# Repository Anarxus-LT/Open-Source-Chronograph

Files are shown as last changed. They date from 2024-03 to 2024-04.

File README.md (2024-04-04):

# Open-Source-Chronograph
 An open source chronograph used to measure the speed and energy of projectiles. Mainly intended for airsoft.
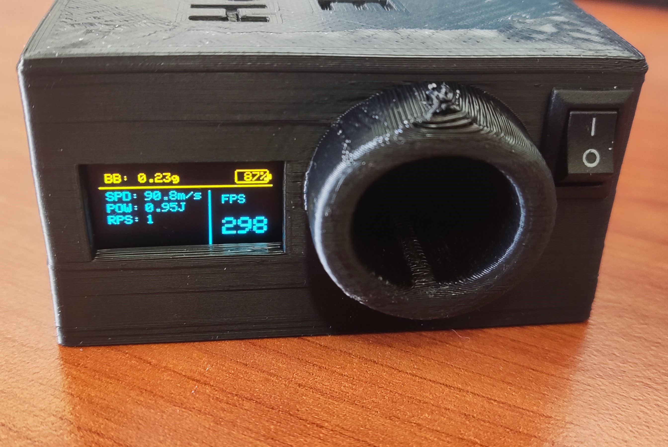
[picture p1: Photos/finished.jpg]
finished
 

## Notes
* If you use phototransistors instead of photodiodes, you will need less components

## Donations :smiley:
Did you find the project useful ? feel free to buy me a cofee :coffee:



No hard feeling if you dont :wink:

## Instructions
To upload the firmware to the pi pico
1. Unplug the usb cable
2. Press the "BOOTSEL" button and hold it
3. Plug the usb cable
4. Copy the "Open_Source_chronograph.ino.uf2" to the drive that showed up

## Components used
* TP4056 module with BMS
* 18650 battery
* 1x small power switch  (I used a generic 10x15mm switch)
* SSD1306 128x64 I2C OLED display
* Pi pico with headers soldered
* 4pin right angle male header
* 2x 20pin female headers
* 5v buzzer
* 3 tactile switches
* 2 IR LEDs (and appropriete resistors)
* 1A fuse

### If using phototransitors
* 2x phototransistors

### if using photodiodes
* 2x photodiodes
* 2x 2n3904 BJT or similar
* 2x 330Ω resistors
* 2x 2.2kΩ resistors

## PCB
I used a protoboard and cut it down to fit the enclosure, you can see the dimensions and hole locations in the photos bellow
**NOTE: ** Both PCBs needed to be trimed 1-2mm more tio fit the enclosure, i will design a better enclosure in the future.

### Main PCB
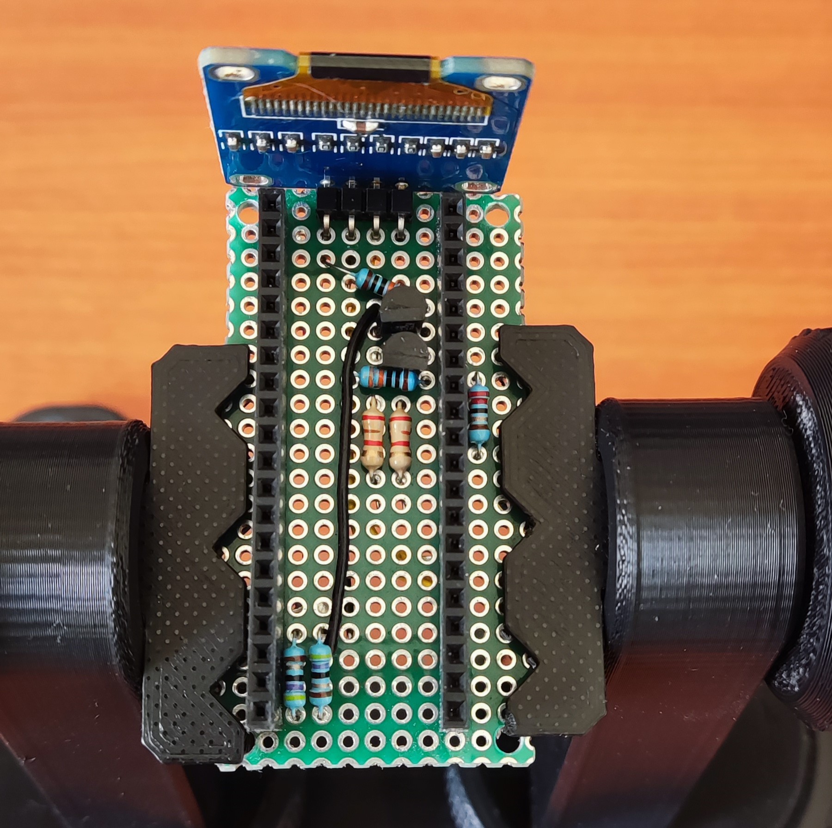
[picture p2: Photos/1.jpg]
Mainpcb 1

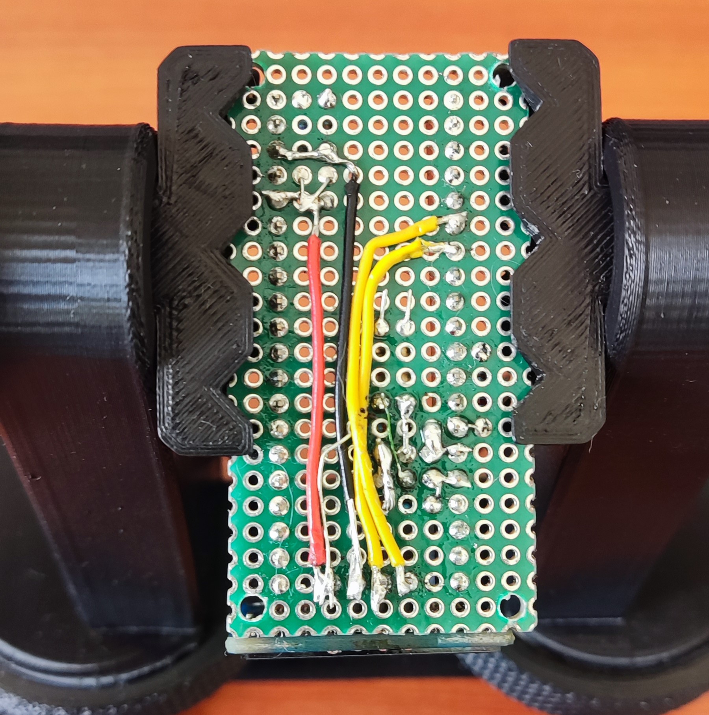
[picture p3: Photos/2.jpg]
Mainpcb 2

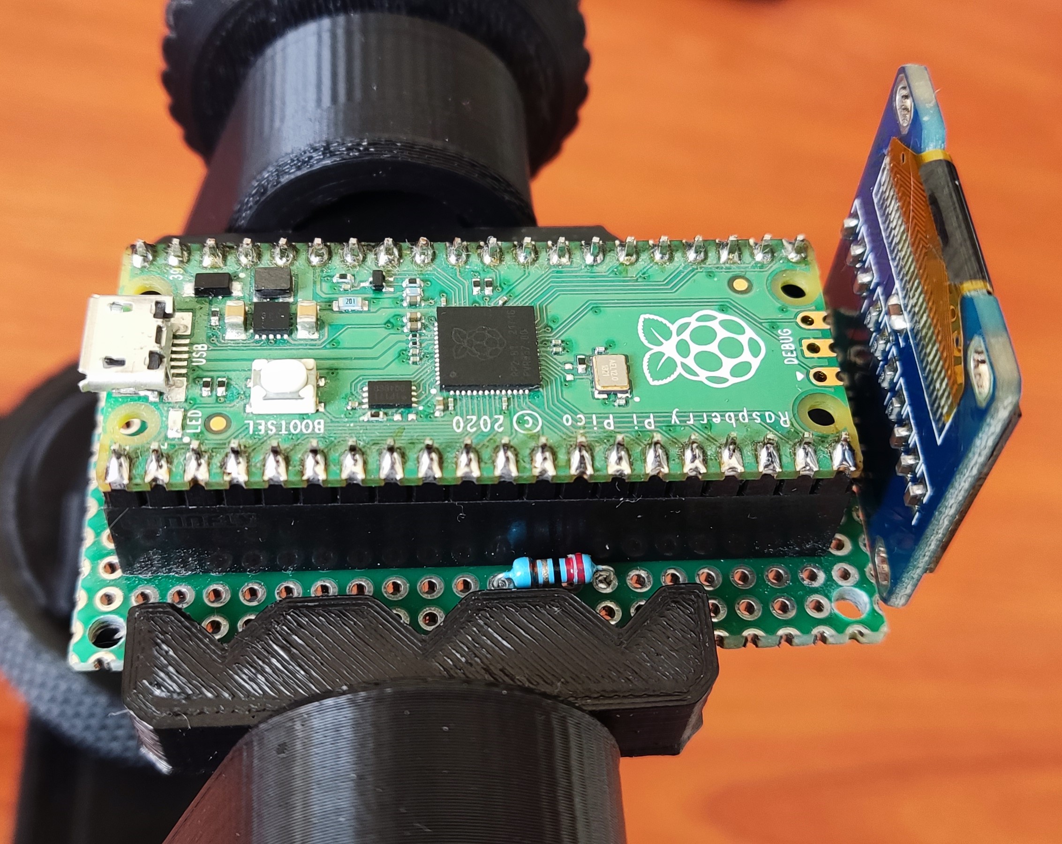
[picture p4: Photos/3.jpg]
Mainpcb 3


### Buttons PCB
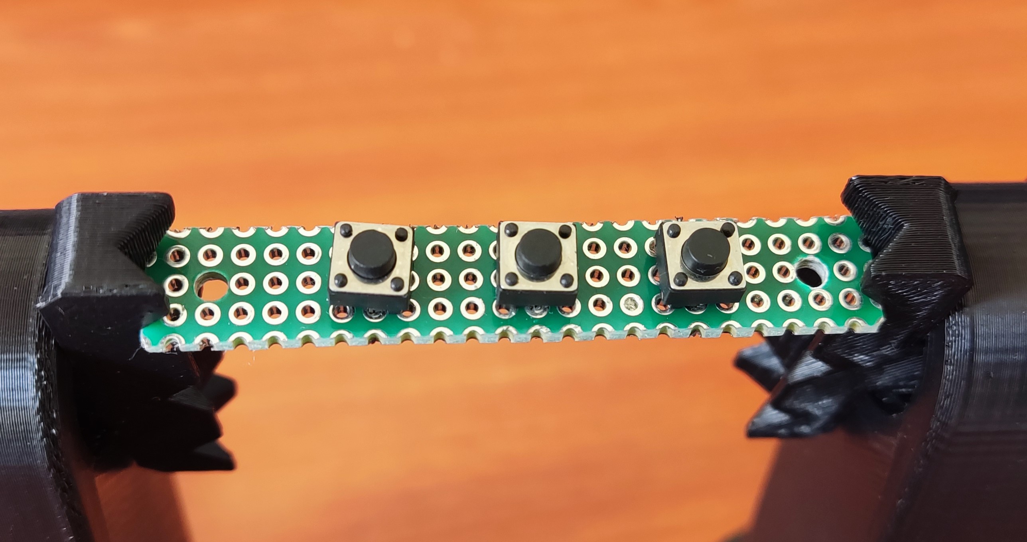
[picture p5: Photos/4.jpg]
buttonspcb 1

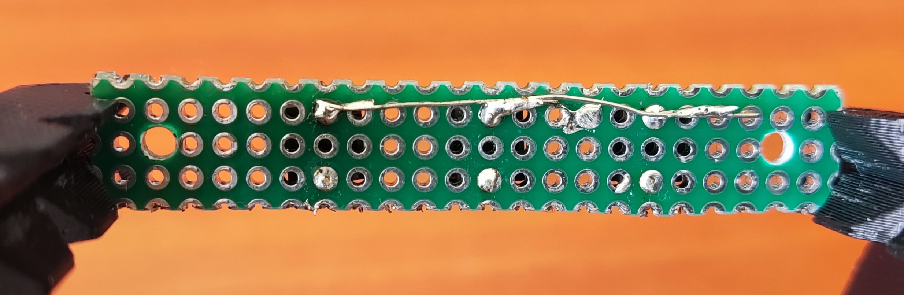
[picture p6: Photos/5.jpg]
buttonspcb 2


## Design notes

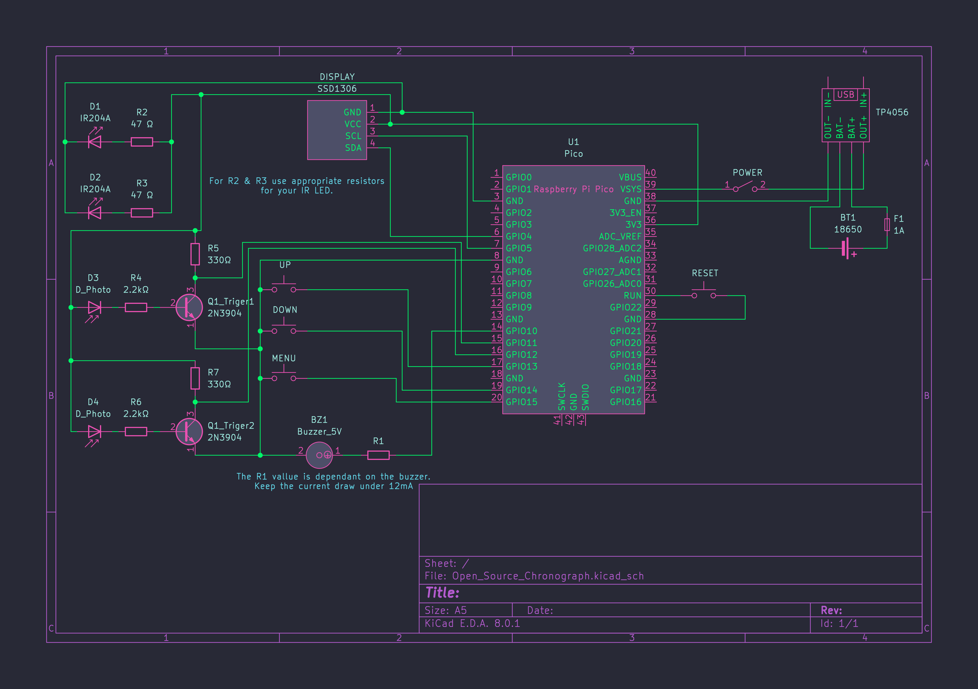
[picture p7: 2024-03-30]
Schematic/Open_Source_Chronograph-with_photodiode/Open_Source_Chronograph-with_photodiode.png

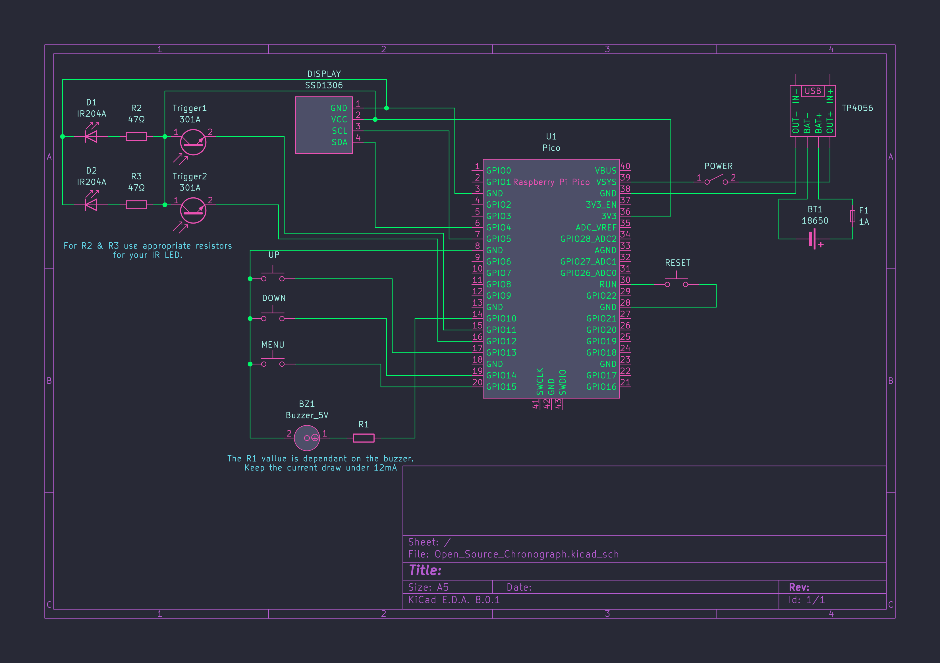
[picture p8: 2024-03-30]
Schematic/Open_Source_Chronograph-with_phototransistor/Open_Source_Chronograph_with_phototransistors.png

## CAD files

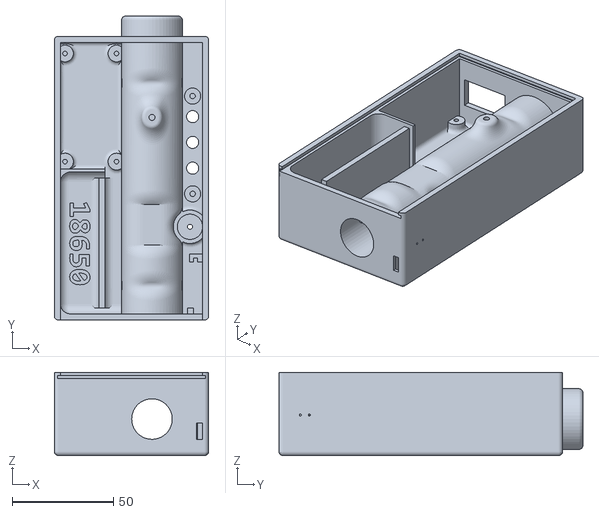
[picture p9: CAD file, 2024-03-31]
CAD/MainBody.stl
76.2 x 150.0 x 41.0

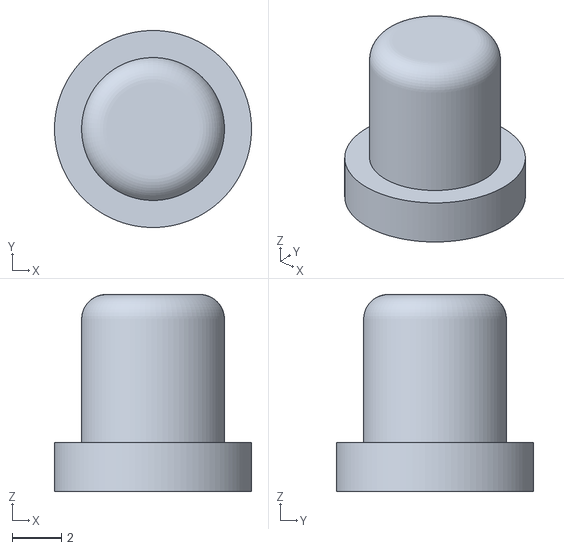
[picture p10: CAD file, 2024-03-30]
CAD/Button.stl
8.00 x 8.00 x 8.00

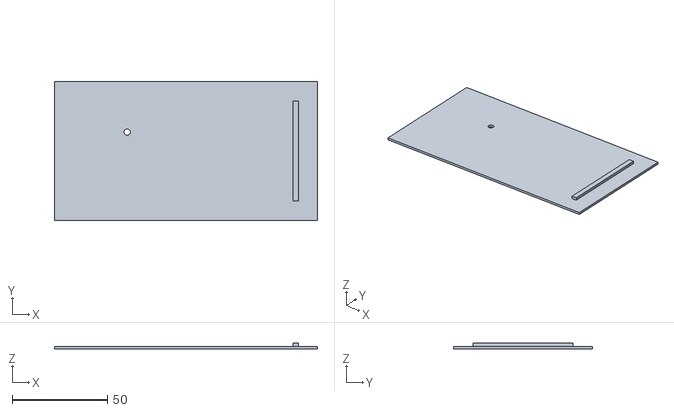
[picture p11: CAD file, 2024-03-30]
CAD/Lid.stl
138.2 x 72.8 x 2.90

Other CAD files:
CAD/Assembly1.iam
CAD/Button.ipt
CAD/Lid.ipt
CAD/MainBody.ipt
CAD/OldVersions/Assembly1.0001.iam
CAD/OldVersions/Button.0002.ipt
CAD/OldVersions/Lid.0002.ipt
CAD/OldVersions/MainBody.0024.ipt

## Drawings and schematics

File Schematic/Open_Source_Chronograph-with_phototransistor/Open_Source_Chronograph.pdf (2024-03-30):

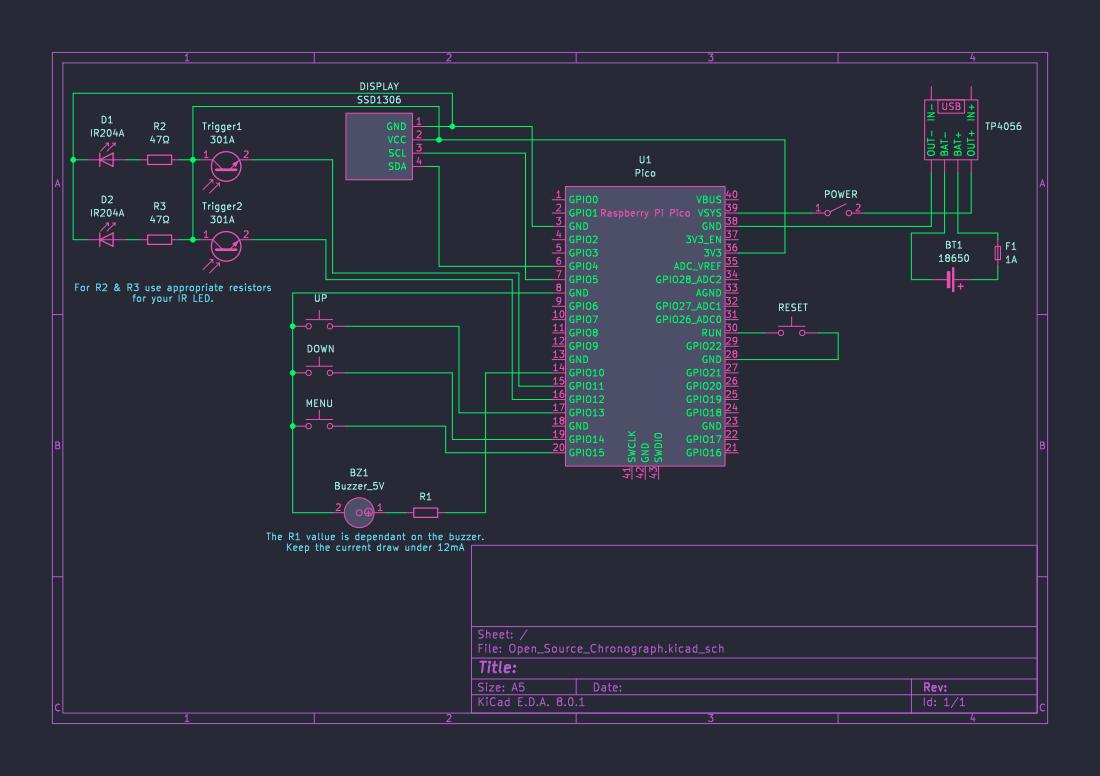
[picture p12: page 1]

for your IR LED.

Id: 1/1 Title: File: Open_Source_Chronograph.kicad_sch Sheet: / UP

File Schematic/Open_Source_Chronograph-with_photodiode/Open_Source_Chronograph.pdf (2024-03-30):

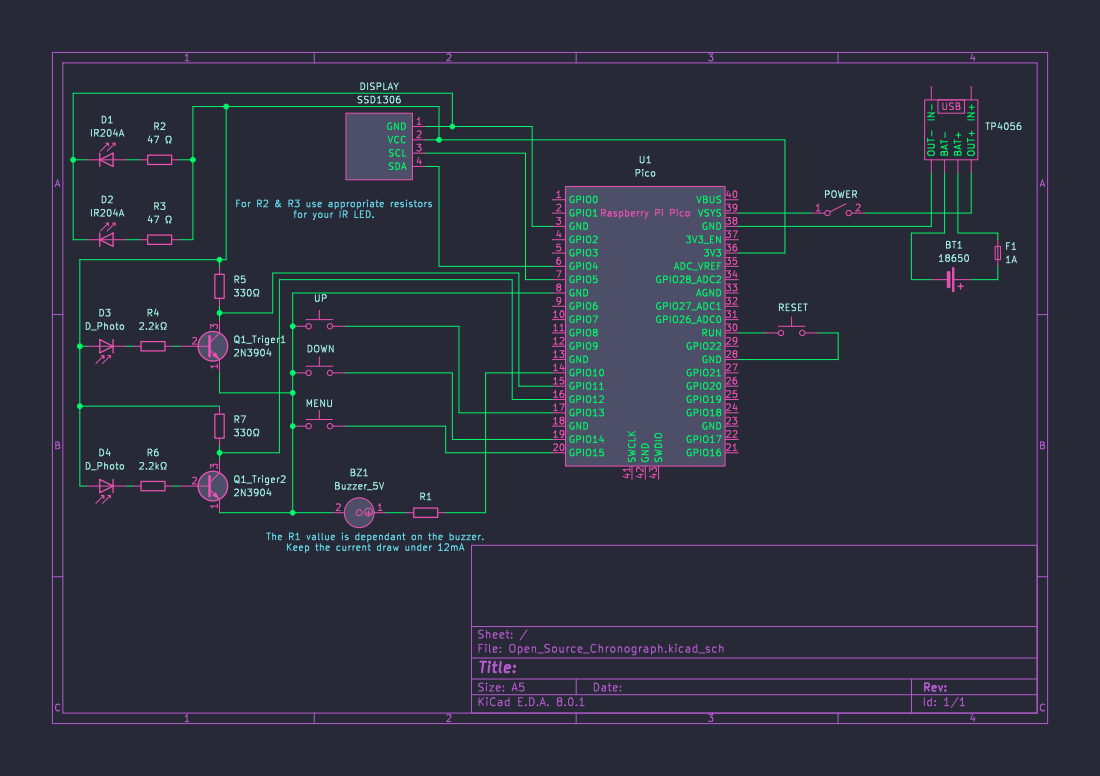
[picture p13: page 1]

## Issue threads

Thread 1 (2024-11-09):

Trigger Level with photo transistors

JoachimF, 2024-11-09:
Hello,

I think the level must be reversed in the code  with the phototransistors.

I try with phototransistor of the CN70.

I'll tell you if it works.

Regards,

Joachim

Anarxus-LT, 2024-11-10:
Hello
What do you mean by level?
Also are you referring to the CNY70 phototransistors? Those seem like a good find and possibly could solve the issues with the detection. Let me know how well they perform.

Have a nice day
Lykourgos

JoachimF, 2024-11-10:
Hello,

Here is the datasheet : https://www.vishay.com/docs/83751/cny70.pdf my finger slip on the Y of CNY.

The is no pullup on your phototransistor schematic : https://github.com/Anarxus-LT/Open-Source-Chronograph/blob/main/Schematic/Open_Source_Chronograph-with_phototransistor/Open_Source_Chronograph_with_phototransistors.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

I haven't the last kicad, so I didn't open the last schematic pearhaps.

Question, why did you use polling instead of interrupt? Normaly, interrupts are more rapid than polling.

For the crash, I haven't RP2040 debugger, It's the first time I use one, but the green led flash 4 time slow the 4 time fast. I identify that was the core2 task  made crash the RP after detected object. Also battery level is always -226. Really strange behavior.

I use STM32 and ESP32 more often.

Joachim

Anarxus-LT, 2024-11-11:
Hello
You are correct the schematic is missing pull down resistors, I will correct it. I used the photodiodes and did not notice the mistake. Regarding the code it should work the same for both versions. It is designed to trigger when the beam is cut. It should trigger in both versions with the only difference is if it triggers when or often it interrupts the beam.

The CNY70 seems like a good solution, the only thing that worries me is the range. From my understanding you are using additional IR LEDs to help with that? In any case let me know how it performs

I avoided interrupts and used the second core for measuring because the display library also used interrupts, and it would cause issues.
Below I have attached in image with the settings I used, I think they were the default. Also are you using the Arduino IDE from the Windows store?

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

The -226 battery level is indeed strange, are you using the standard PICO? or the PICO W or PICO 2?
Also, what board library are you using? i am using this [one](https://github.com/earlephilhower/arduino-pico)

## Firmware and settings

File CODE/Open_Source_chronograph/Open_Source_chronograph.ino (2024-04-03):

/*

 ___________ _____ _   _   _____  _____ _   _______  _____  _____      
|  _  | ___ \  ___| \ | | /  ___||  _  | | | | ___ \/  __ \|  ___|     
| | | | |_/ / |__ |  \| | \ `--. | | | | | | | |_/ /| /  \/| |__       
| | | |  __/|  __|| . ` |  `--. \| | | | | | |    / | |    |  __|      
\ \_/ / |   | |___| |\  | /\__/ /\ \_/ / |_| | |\ \ | \__/\| |___      
 \___/\_|   \____/\_| \_/ \____/  \___/ \___/\_| \_| \____/\____/      
                                                                       
                                                                       
 _____  _   _ ______ _____ _   _ _____ _____ ______  ___  ______ _   _ 
/  __ \| | | || ___ \  _  | \ | |  _  |  __ \| ___ \/ _ \ | ___ \ | | |
| /  \/| |_| || |_/ / | | |  \| | | | | |  \/| |_/ / /_\ \| |_/ / |_| |
| |    |  _  ||    /| | | | . ` | | | | | __ |    /|  _  ||  __/|  _  |
| \__/\| | | || |\ \\ \_/ / |\  \ \_/ / |_\ \| |\ \| | | || |   | | | |
 \____/\_| |_/\_| \_|\___/\_| \_/\___/ \____/\_| \_\_| |_/\_|   \_| |_/
                                                                       
==========================================================================
Read LICENCE
Description: An open source chronograph used to measure the speed and 
            energy of projectiles. Mainly intended for airsoft.
Author: Lykourgos Tanious

*/

#include <Wire.h>
#include <Adafruit_GFX.h>
#include <Adafruit_SSD1306.h>
#include "pico/multicore.h"



#define SCREEN_WIDTH 128
#define SCREEN_HEIGHT 64
#define UpButtonPin 13
#define DownButtonPin 14
#define MenuButtonPin 15
#define Trigger1 11
#define Trigger2 12
#define BuzzerPin 10
#define SensorDistance 100 // in mm


Adafruit_SSD1306 display(SCREEN_WIDTH, SCREEN_HEIGHT, &Wire, -1);

// Variable decleration
String batper = "";
int bat = 0;
float vbat= 0;
int selector = 0;
float bbweight = 0.23;
float speedmet = 0;
float powerj = 0;
int rps = 0;
int fps = 0;
int shotcounter = 0;
int UIupdate = 0;
unsigned long UIlastUpdate = 0;
volatile bool ButtUpInt = false;
volatile bool ButDownInt = false;
volatile bool ButMenuInt = false;
// time2-time1 1025 gives 320fps for tests
volatile unsigned long time1 = 0;
volatile unsigned long time2 = 0;
unsigned long firstshottime = 0;

void setup() {
  Serial.begin(9600);
  display.begin(SSD1306_SWITCHCAPVCC, 0x3C);
  delay(2000);
  display.clearDisplay();
  //Init buzzer
  // Make sure it does not draw more than 12 mA, use resistor if needed
  pinMode (BuzzerPin, OUTPUT_12MA);
  // Boot splash
  Splash();
  // Main display UI init
  display.drawLine(0, 14, 128, 14, WHITE);
  update_battery();
  display.setTextSize(1);
  display.setCursor(5,3);
  display.print("BB: " + String(bbweight) + "g");
  display.setCursor(5,16);
  display.print("SPD: " + String(speedmet) + "m/s");
  display.setCursor(5,26);
  display.print("POW: " + String(powerj) + "J");
  display.setCursor(5,36);
  display.print("RPS: " + String(rps));
  display.drawLine(80, 16, 80, 64, WHITE);
  display.setCursor(90,20);
  display.print("FPS");
  display.setTextSize(2);
  display.setCursor(90,40);
  display.print(fps);
  display.display();

  //init buttons
  pinMode (UpButtonPin, INPUT_PULLUP);
  pinMode (DownButtonPin, INPUT_PULLUP);
  pinMode (MenuButtonPin, INPUT_PULLUP);
  attachInterrupt(UpButtonPin, ButtUpInt_f, LOW );
  attachInterrupt(DownButtonPin, ButDownInt_f, LOW );
  attachInterrupt(MenuButtonPin, ButMenuInt_f, LOW );

  //Init IR Triggers
  pinMode (Trigger1, INPUT);
  pinMode (Trigger2, INPUT);

  //Launch second core
  multicore_launch_core1(core1_IR_Triggers);

}

void loop() {
  // menu button selector handling
  switch(selector){
    case 0:
      break;
    case 1:
      display.fillRect(0, 0, 25, 10, BLACK);
      display.display();
      delay(250);
      display.setTextSize(1);
      display.setCursor(5,3);
      display.print("BB: ");
      display.display();
      delay(250);
      break;
  }
  // Button interupt functions
  if (ButMenuInt == true){
    ButMenu();
  }else if (ButDownInt == true){
    ButDown();
  }else if (ButtUpInt == true){
    ButUp();
  }

  // Measure RPS
  if ((shotcounter == 1) && (firstshottime == 0)){
    firstshottime=millis();
  }
  if (((millis()-firstshottime)>1000) && shotcounter != 0){
    rps = shotcounter;
    rpsdisp();
    shotcounter = 0;
    firstshottime = 0;
    message("Wait");
    delay(2000);
    message("Go !");
  }

  // update UI after 10s
  if (UIupdate == 0){
    UIlastUpdate=millis();
    UIupdate = 1;
  }
  if ((millis()-UIlastUpdate)>10000){
    update_battery();
    message("");
    UIupdate = 0;
  }

  // Detect failed read after 1s
  if (((micros() - time1) > 1000000) && time1 != 0){
    time1 = 0;
    time2 = 0;
    message("Retry");
    tone(BuzzerPin, 500, 750);
  }
  if (((micros() - time2) > 1000000) && time2 != 0){
    time1 = 0;
    time2 = 0;
    message("Retry");
    tone(BuzzerPin, 500, 750);
  }


}

void core1_IR_Triggers(){
  while (true){
      while(digitalRead(Trigger1)==LOW);
      while(digitalRead(Trigger1)==HIGH);
      time1=micros();
      while(digitalRead(Trigger2)==LOW);
      while(digitalRead(Trigger2)==HIGH);
      time2=micros();
      if (time1 != 0 && time2 != 0){
      //Got a sucessful read
      fps = floor(0.32808398950131235/((float(time2)-float(time1))/1000000.0));
      message("PEW !");
      fpsdisp(fps);
      msdisp(fps);
      powdisp();
      time1 = 0;
      time2 = 0;
      shotcounter++;
      tone(BuzzerPin, 3000, 500);
      }
  }
}


void rpsdisp(){
  display.fillRect(27, 36, 53, 10, BLACK);
  display.setTextSize(1);
  display.setCursor(27,36);
  display.print(" " + String(rps));
  display.display();
}

void powdisp(){
  powerj = 0.5 * float(bbweight/1000.0) * sq(speedmet);
  display.fillRect(27, 26, 53, 10, BLACK);
  display.setTextSize(1);
  display.setCursor(27,26);
  display.print(" " + String(powerj, 2) + "J");
  display.display();
}

void msdisp(int fps){
  speedmet = fps * 0.3048;
  display.fillRect(27, 16, 53, 10, BLACK);
  display.setTextSize(1);
  display.setCursor(27,16);
  display.print(" " + String(speedmet, 1) + "m/s");
  display.display();
}

void fpsdisp(int fps){
  String fpsstring = String(fps);
  display.fillRect(90, 40, 128, 64, BLACK);
  display.setTextSize(2);
  display.setCursor(90,40);
  display.print(fps);
  display.display();
}

void message(String msg){
  delay(250); //without this delay the display glitches for some reason
  display.fillRect(5, 50, 65, 15, BLACK);
  display.setTextSize(1);
  display.setCursor(5,50);
  display.print(msg);
  display.display();
}

void ButtUpInt_f(){
  ButtUpInt = true;
}
void ButDownInt_f(){
  ButDownInt = true;
}
void ButMenuInt_f(){
  ButMenuInt = true;
}

void ButUp(){
  switch(selector){
    case 0:
      break;
    case 1:
      bbweight += 0.01;
      updatebb_weight();
      powdisp();
      tone(BuzzerPin, 2000, 250);
      break;
  }
  ButtUpInt = false;
}

void ButDown(){
  switch(selector){
    case 0:
      break;
    case 1:
      bbweight -= 0.01;
      updatebb_weight();
      powdisp();
      tone(BuzzerPin, 2000, 250);
      break;
  }
  ButDownInt = false;
}

void ButMenu(){
  selector++;
  if (selector>1){
    selector=0;
  }
  delay(200);
  ButMenuInt = false;
  tone(BuzzerPin, 1000, 250);
}

void updatebb_weight(){
  display.fillRect(25, 0, 50, 10, BLACK);
  display.setTextSize(1);
  display.setCursor(5,3);
  display.print("BB: " + String(bbweight) + "g");
  display.display();
  delay(200);
}

void update_battery(){
  vbat = analogRead(29)/100.0;
  bat = ceil(((vbat-3)/(4.2-3))*100);

  if (bat == 100){
    batper = ""+String(bat) + "%";
  }else if (bat < 100 && bat >= 10){
    batper = " "+String(bat) + "%";
  }else if (bat>1 && bat < 10){
    batper = "  "+String(bat) + "%";
  }else if (bat > 100){
    batper = " EXT";
  }else if (bat < 1){
    batper = " LOW";
    display.fillRoundRect(100, 1, 30, 11, 2, BLACK);
    display.display();
    tone(BuzzerPin, 3000, 150);
    delay(1000);
  }
  display.fillRoundRect(100, 1, 25, 11, 2, BLACK);
  display.drawRoundRect(100, 1, 25, 11, 2, WHITE);
  display.fillRect(125, 5, 2, 4, WHITE);
  display.setTextSize(0);
  display.setTextColor(WHITE);
  display.setCursor(101, 3);
  display.println(batper);
  display.display();
}

void bootsound(){
  digitalWrite(BuzzerPin, HIGH);
  delay(500);
  digitalWrite(BuzzerPin, LOW);
  delay(500);
}
void Splash(){
  display.setTextSize(1);
  display.setTextColor(WHITE);
  display.setCursor(40, 0);
  display.println("ANARXUS");
  display.setTextSize(2);
  display.setCursor(35, 20);
  display.println("OPEN");
  display.setCursor(25, 40);
  display.println("CHRONO");
  display.display();
  bootsound();
  display.clearDisplay();
  display.display();
}

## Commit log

2024-03-18 Created required directories for Arduino IDE
2024-03-19 Feature implementation
    Added metric speed, power and rps functions. Waiting for ir parts to create the triggers
2024-03-20 Started schematic design
    [Schematic.sch]
2024-03-21 Continued schematic
    [Schematic.sch]
2024-03-21 KiCad schematics
    Trying KiCad because i did not like eagle
    [Open_Source_Chronograph.kicad_pcb, Open_Source_Chronograph.kicad_sch]
2024-03-22 Schematic update
    Removed Eagle CAD schematics and recreated with KiCAD.
    Triggers will be implemented when IR LEDs arrive
    [Open_Source_Chronograph.kicad_sch, Schematic.sch]
2024-03-26 Schematic update & firmware testing
    Expected phototransistors, got photodiodes. I created a second schematic and i will add transistors to the photodiodes.
    Doing tests
    [Open_Source_Chronograph.kicad_pcb, Open_Source_Chronograph.kicad_sch]
2024-03-30 Started enclosure design and added a fuse
    [MainBody.0011.ipt, MainBody.ipt, Open_Source_Chronograph.kicad_sch]
2024-03-30 Completed enclosure design
    The design is a basic prototype and has some issues. Should be redesigned better in the future.
    [Assembly1.0001.iam, Assembly1.iam, Button.0002.ipt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]
2024-03-30 Added fuse and exported schematics
    [Open_Source_Chronograph.kicad_sch]
2024-03-31 Updated CAD model
    Added some cosmetic changes
    [MainBody.0022.ipt, MainBody.0024.ipt, MainBody.ipt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]
2024-04-03 Fixed bugs, rewrote trigger code
    Fixed incorrect bad read
    Fixed RPS logical error
    Rewrote the trigger code to run on the second core without interrupts for better accuracy.
    Moved UI update code to main loop and kept the same functionality.
    Tested it, results seem accurate.
    [Open_Source_chronograph.ino]
